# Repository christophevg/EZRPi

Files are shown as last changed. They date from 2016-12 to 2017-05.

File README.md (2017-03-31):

# EZRPi
Raspberry Pi HAT with a Silicon Labs EZR32 Sub-GHz MCU  
Christophe VG (<contact@christophe.vg>)  
[http://christophe.vg/embedded/EZRPi](http://christophe.vg/embedded/EZRPi)

## Introduction

Using the EZRPi HAT one can give access to sub-GHz network protocols to a Raspberry Pi. An example of such protocol is Dash7. Dash7 is a specification for an ultra low power network stack, operating within the sub-GHz spectrum. The [Dash7 Open Source Stack (OSS-7)](https://github.com/MOSAIC-LoPoW/dash7-ap-open-source-stack) can be flashed onto the EZR to turn it into a modem, accessible from the Raspberry Pi. On the Pi, one then could talk to this modem using [pyd7a](https://github.com/MOSAIC-LoPoW/pyd7a) a collection of Python modules, supporting the DASH7 Alliance Protocol in general, and OSS-7 in particular..

This repository contains all design and implementation source files of this generic sub-GHz Raspberry Pi HAT.

## Version 1

On Thursday March 30, I was able to assemble the first EZRPi:

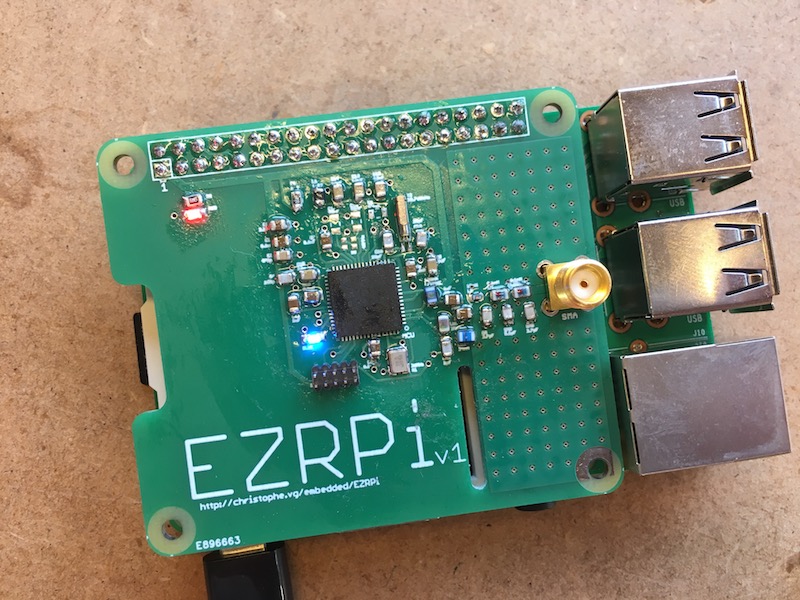
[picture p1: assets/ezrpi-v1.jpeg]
EZRPi v1


The design includes a standard 868MHz setup of the EZR32 and two LEDs for minimal debugging/feedback.

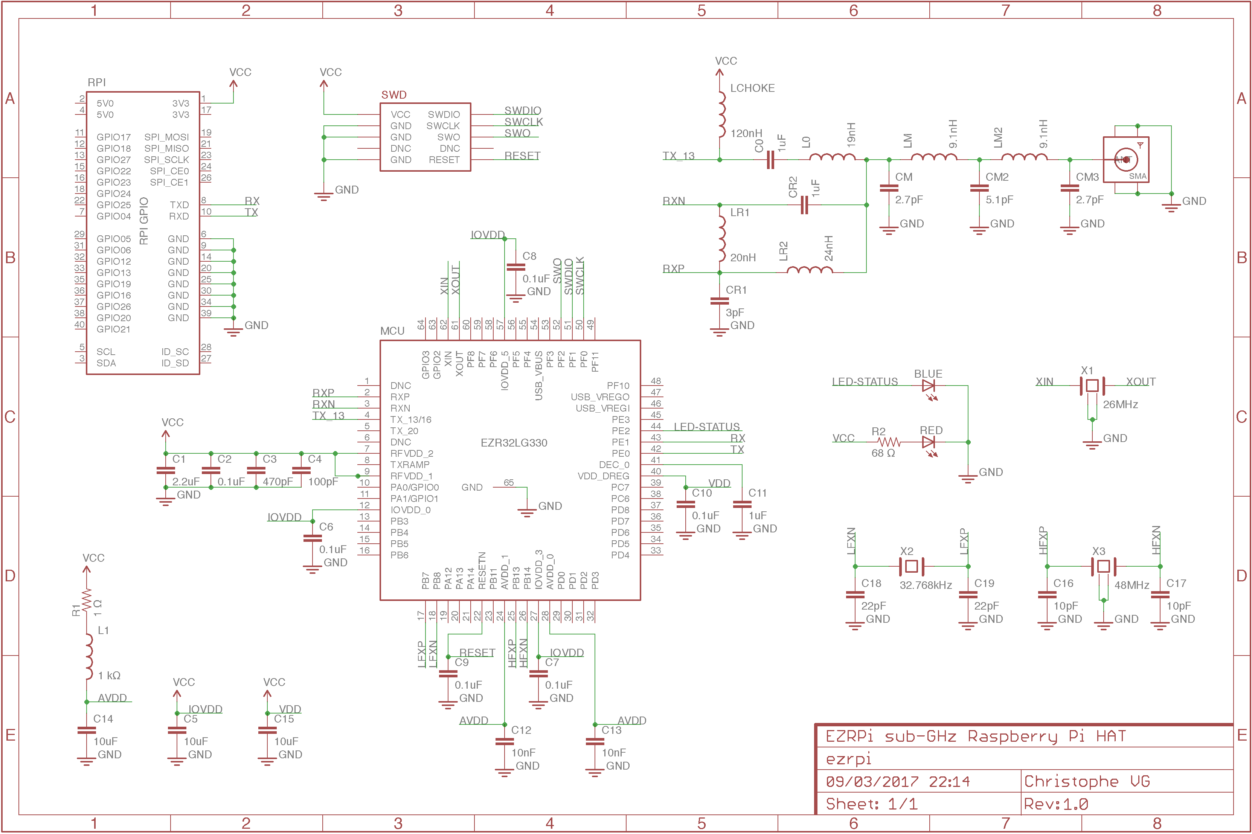
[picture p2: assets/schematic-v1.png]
Schematic v1


The board is a 2-layer PCB based on the official Raspberry Pi HAT board specification.

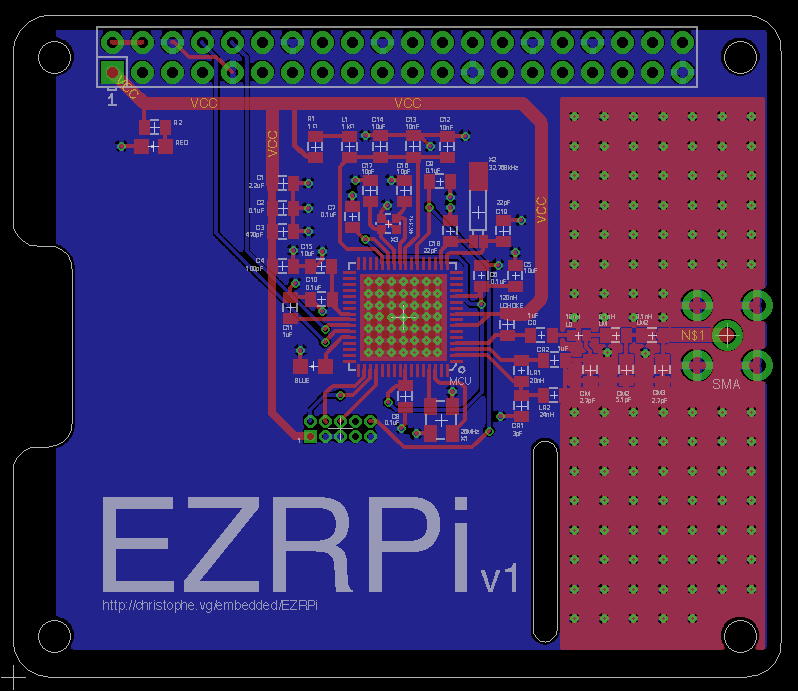
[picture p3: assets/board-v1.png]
Board v1


## Software

In the `src/` folder a first small test application is included: [`blink`](src/blink). It requires the `Gecko SDK`, which is included as a submodule in the `lib/` folder.

### OSS-7 Support

As of [Friday March 21](https://github.com/MOSAIC-LoPoW/dash7-ap-open-source-stack/pull/51), the [Dash7 Open Source Stack](https://github.com/MOSAIC-LoPoW/dash7-ap-open-source-stack) now also includes a platform definition for the EZRPi. This makes it super-easy to add Dash7 support to the Raspberry Pi:

```bash
$ git clone https://github.com/MOSAIC-LoPoW/dash7-ap-open-source-stack
Cloning into 'dash7-ap-open-source-stack'...
remote: Counting objects: 39483, done.
remote: Compressing objects: 100% (291/291), done.
remote: Total 39483 (delta 164), reused 0 (delta 0), pack-reused 39191
Receiving objects: 100% (39483/39483), 71.42 MiB | 8.46 MiB/s, done.
Resolving deltas: 100% (27893/27893), done.

$ cd dash7-ap-open-source-stack

$ mkdir build

$ cd build

$ cmake ../stack/ \
        -DCMAKE_TOOLCHAIN_FILE=../stack/cmake/toolchains/gcc-arm-embedded.cmake \
        -DPLATFORM=EZRPi \
        -DAPP_SENSOR_PUSH=on \
        -DFRAMEWORK_LOG_ENABLED=yes \
        -DFRAMEWORK_DEBUG_ASSERT_MINIMAL=y
-- Cross-compiling using gcc-arm-embedded toolchain
-- Cross-compiling using gcc-arm-embedded toolchain
-- The C compiler identification is GNU 4.9.3
-- The CXX compiler identification is GNU 4.9.3
-- Detecting C compiler ABI info
-- Detecting C compiler ABI info - failed
-- Detecting C compile features
-- Detecting C compile features - failed
-- Detecting CXX compiler ABI info
-- Detecting CXX compiler ABI info - failed
-- Detecting CXX compile features
-- Detecting CXX compile features - failed
-- detected supported platforms: EFM32GG_STK3700 EFM32HG_STK3400 EZR32LG_Octa EZR32LG_USB01 EZR32LG_WSTK6200A EZRPi OCTA_Gateway stm32f4_discovery
-- selected platform: EZRPi
-- The ASM compiler identification is GNU
-- Found assembler: /usr/local/bin/arm-none-eabi-gcc
-- Added chip ezr32lg
-- Added chip si4460
-- Configuring done
-- Generating done
-- Build files have been written to: /Users/xtof/dash7-ap-open-source-stack/build

$ make
Scanning dependencies of target CHIP_SI4460
[  1%] Building C object framework/hal/platforms/platform/chips/si4460/CMakeFiles/CHIP_SI4460.dir/si4460.c.obj
...
[ 98%] Building C object apps/sensor_push/CMakeFiles/sensor_push.elf.dir/version.c.obj
[100%] Linking C executable sensor_push.elf
[100%] Built target sensor_push.elf

$ make flash-sensor_push
[ 14%] Built target d7ap
[ 22%] Built target CHIP_SI4460
...
Downloading file [sensor_push.bin]...
Comparing flash   [100%] Done.
Erasing flash     [100%] Done.
Programming flash [100%] Done.
Verifying flash   [100%] Done.
J-Link: Flash download: Flash programming performed for 3 ranges (77824 bytes)
J-Link: Flash download: Total time needed: 1.960s (Prepare: 0.052s, Compare: 0.062s, Erase: 0.933s, Program: 0.896s, Verify: 0.008s, Restore: 0.007s)
O.K.

Loading binary file sensor_push.bin
Reading 81476 bytes data from target memory @ 0x00000000.
Verify successful.

Reset delay: 0 ms
Reset type NORMAL: Resets core & peripherals via SYSRESETREQ & VECTRESET bit.

Script processing completed.

[100%] Built target flash-sensor_push

```

The EZRPi has been tested against the EZR32LG_USB01 and bi-directional communication was achieved.

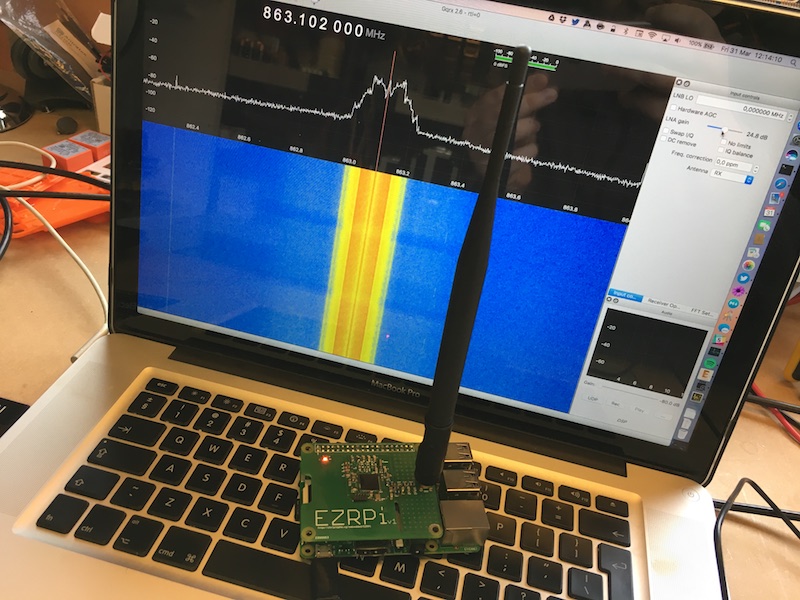
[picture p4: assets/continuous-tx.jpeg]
It's Alive


## Thanks

Although merely a software-implementation option, many thanks go out to the Dash7 Alliance and the OSS-7 team for creating the Dash7 network stack specification in all openness. Special thanks go out to Maarten W. for his support in making this project a reality.

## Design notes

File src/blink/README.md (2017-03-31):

# EZRPi Blink

This example is the most basic example for testing the minimal capabilities of the EZRPi. It only uses the standard [Gecko SDK](../lib/Gecko_SDK) to blink the blue LED.

## Setup

Mount the EZRPi on a Raspberry Pi and power the Pi. The red led near the Pi header should light up, indicating that the EZRPi also is powered.

## Building

```bash
$ make
*** compiling ../../lib/Gecko_SDK/platform/Device/SiliconLabs/EZR32LG/Source/system_ezr32lg.c
*** assembling ../../lib/Gecko_SDK/platform/Device/SiliconLabs/EZR32LG/Source/GCC/startup_ezr32lg.S
*** compiling ../../lib/Gecko_SDK/platform/emlib/src/em_assert.c
*** compiling ../../lib/Gecko_SDK/platform/emlib/src/em_cmu.c
*** compiling ../../lib/Gecko_SDK/platform/emlib/src/em_ebi.c
*** compiling ../../lib/Gecko_SDK/platform/emlib/src/em_emu.c
*** compiling ../../lib/Gecko_SDK/platform/emlib/src/em_gpio.c
*** compiling ../../lib/Gecko_SDK/platform/emlib/src/em_system.c
*** compiling ../../lib/Gecko_SDK/platform/emlib/src/em_usart.c
*** compiling blink.c
*** linking .build/blink.out
*** creating .build/blink.bin
```

## Programming

To program the EZR32, I use a programmer and software from [Segger](https://www.segger.com). Other solutions are possible, but I'm not covering them.

```bash
$  make program
*** generating programming script .build/flash.script
*** programming
SEGGER J-Link Commander V6.14b (Compiled Mar  9 2017 08:48:44)
DLL version V6.14b, compiled Mar  9 2017 08:48:31
...
Downloading file [blink/blink.bin]...
Comparing flash   [100%] Done.
Erasing flash     [100%] Done.
Programming flash [100%] Done.
Verifying flash   [100%] Done.
J-Link: Flash download: Flash programming performed for 1 range (6144 bytes)
J-Link: Flash download: Total time needed: 0.184s (Prepare: 0.066s, Compare: 0.004s, Erase: 0.000s, Program: 0.103s, Verify: 0.001s, Restore: 0.009s)
O.K.
Reset delay: 0 ms
Reset type NORMAL: Resets core & peripherals via SYSRESETREQ & VECTRESET bit.

```

You now should have a blinking blue led near the lower left corner of the microcontroller.

EZRPi v1

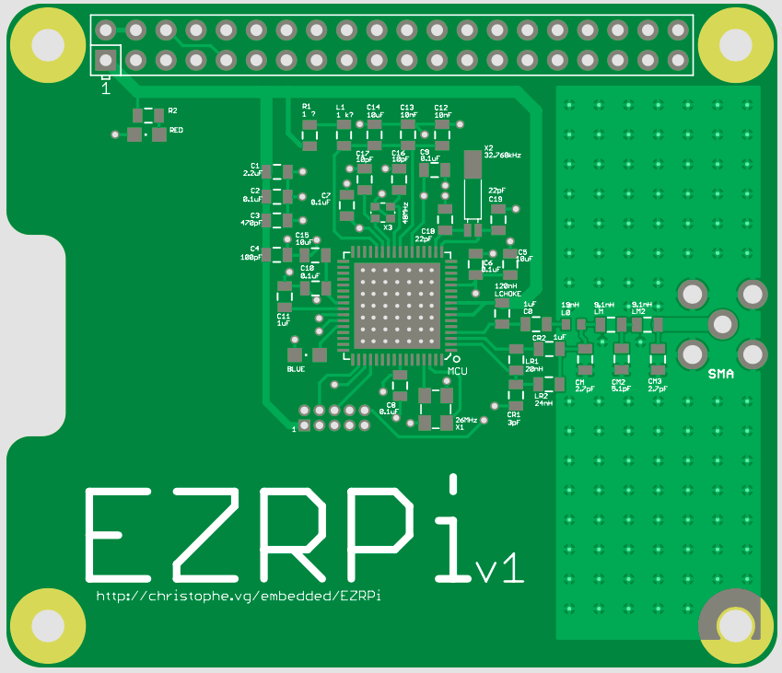
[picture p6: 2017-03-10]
assets/ec-v1.png

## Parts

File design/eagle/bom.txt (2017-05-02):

Partlist exported from /Users/xtof/Workspace/EZRPi/design/eagle/ezrpi.sch at 31/03/2017 21:42

Qty Value      Device           Package                 Parts                   Description   
2              LEDCHIPLED_0805  CHIPLED_0805            BLUE, RED               LED           
1              SMACONNECTOR     SMA90_DIP               SMA                     SMA Connector 
6   0.1uF      CAP0805          0805                    C2, C6, C7, C8, C9, C10 Capacitor     
1   1 kΩ       INDUCTOR0805     0805                    L1                      Inductors     
1   1 Ω        RESISTOR0805-RES 0805                    R1                      Resistor      
1   100pF      CAP0805          0805                    C4                      Capacitor     
2   10nF       CAP0805          0805                    C12, C13                Capacitor     
2   10pF       CAP0805          0805                    C16, C17                Capacitor     
3   10uF       CAP0805          0805                    C5, C14, C15            Capacitor     
1   120nH      INDUCTOR0805     0805                    LCHOKE                  Inductors     
1   19nH       INDUCTOR0402     C0402                   L0                      Inductors     
3   1uF        CAP0805          0805                    C0, C11, CR2            Capacitor     
1   2.2uF      CAP0805          0805                    C1                      Capacitor     
2   2.7pF      CAP0805          0805                    CM, CM3                 Capacitor     
1   20nH       INDUCTOR0805     0805                    LR1                     Inductors     
2   22pF       CAP0805          0805                    C18, C19                Capacitor     
1   24nH       INDUCTOR0805     0805                    LR2                     Inductors     
1   26MHz      ABM8             ABM8                    X1                                    
1   32.768kHz  MS3V-T1R         MS3V-T1R                X2                                    
1   3pF        CAP0805          0805                    CR1                     Capacitor     
1   470pF      CAP0805          0805                    C3                      Capacitor     
1   48MHz      ABM11            ABM11                   X3                                    
1   5.1pF      CAP0805          0805                    CM2                     Capacitor     
1   68 Ω       RESISTOR0805-RES 0805                    R2                      Resistor      
2   9.1nH      INDUCTOR0805     0805                    LM, LM2                 Inductors     
1   EZR32LG330 EZR32LG330       QFN64G-0.5-9X9MM        MCU                                   
1   FTSH2X5    FTSH2X5          HEADER2X5               SWD                                   
1   RPI3_HAT   RPI3_HAT         RASPI_BOARD_B+HAT_DF_CF RPI

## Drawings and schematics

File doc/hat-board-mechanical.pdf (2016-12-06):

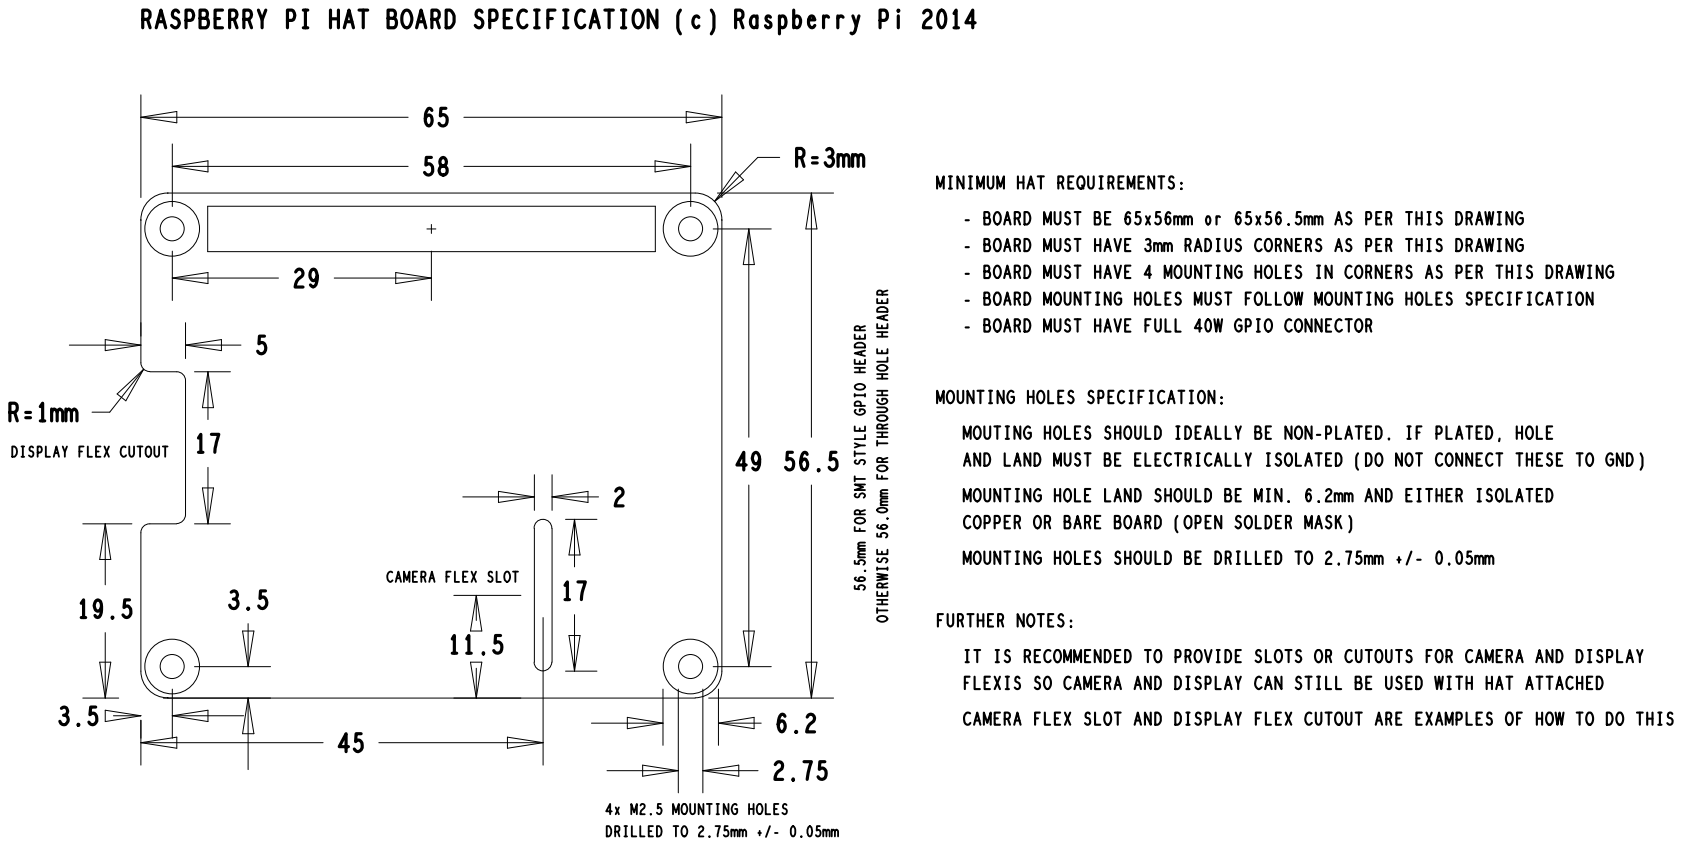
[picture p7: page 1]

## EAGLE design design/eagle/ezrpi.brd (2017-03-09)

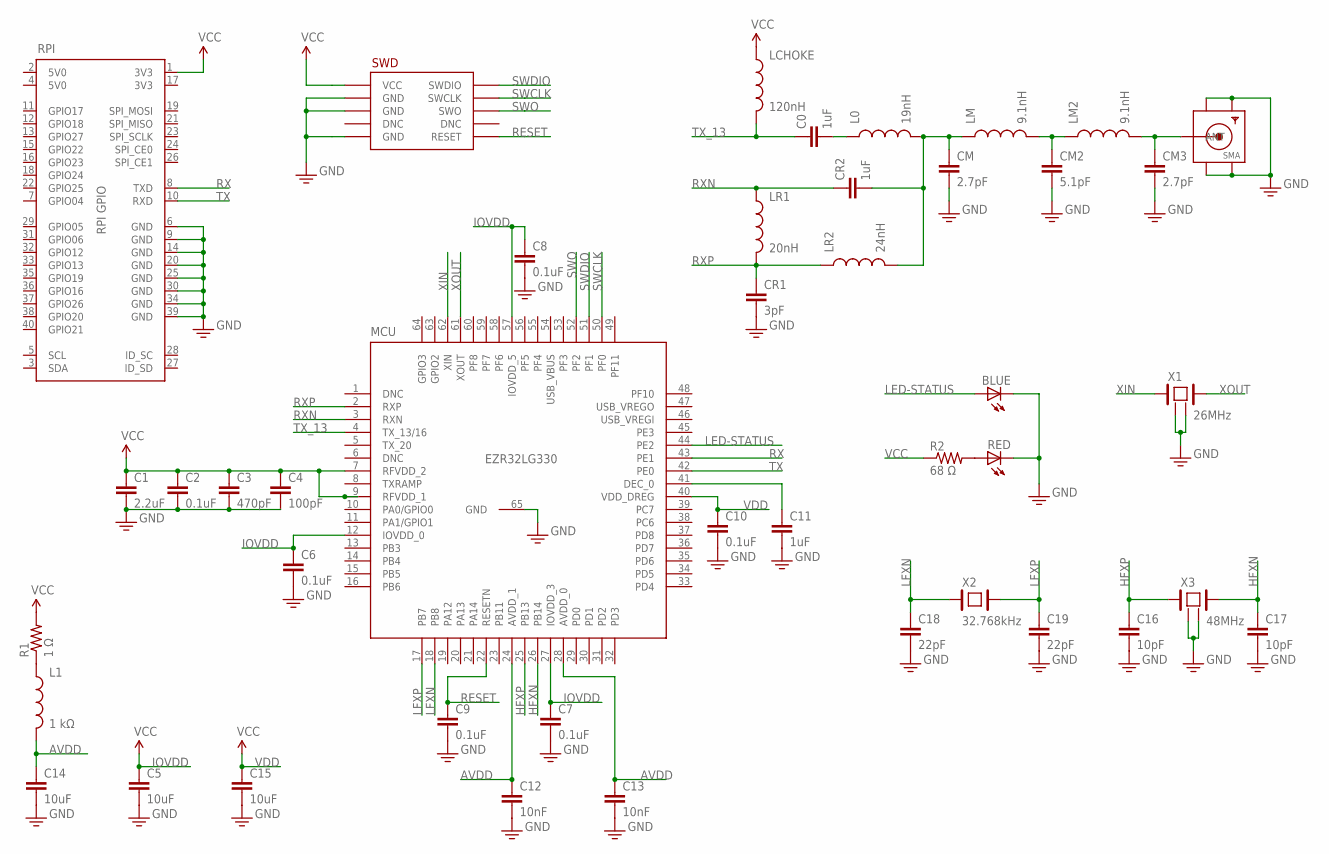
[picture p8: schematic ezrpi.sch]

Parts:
BLUE: LEDCHIPLED_0805; CHIPLED_0805
C0, C11: 1uF; 0805
C1: 2.2uF; 0805
C2, C6, C7, C8, C9, C10: 0.1uF; 0805
C3: 470pF; 0805
C4: 100pF; 0805
C5, C14, C15: 10uF; 0805
C12, C13: 10nF; 0805
C16, C17: 10pF; 0805
C18, C19: 22pF; 0805
CM, CM3: 2.7pF; 0805
CM2: 5.1pF; 0805
CR1: 3pF; 0805
CR2: 1uF; 0805
L0: 19nH; C0402
L1: 1 kΩ; 0805
LCHOKE: 120nH; 0805
LM, LM2: 9.1nH; 0805
LR1: 20nH; 0805
LR2: 24nH; 0805
MCU: EZR32LG330; QFN64G-0.5-9X9MM
R1: 1 Ω; 0805
R2: 68 Ω; 0805
RED: LEDCHIPLED_0805; CHIPLED_0805
RPI: RPI3_HAT; RASPI_BOARD_B+HAT_DF_CF
SMA: SMACONNECTOR; SMA90_DIP
SWD: FTSH2X5; HEADER2X5
X1: 26MHz; ABM8
X2: 32.768kHz; MS3V-T1R
X3: 48MHz; ABM11

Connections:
3V3: RPI.17 (3V3)
5V0: RPI.2 (5V0), RPI.4 (5V0)
AVDD: C12.1, C13.1, C14.1, L1.2, MCU.24 (AVDD_1), MCU.28 (AVDD_0)
GND: BLUE.C, C1.2, C2.2, C3.2, C4.2, C5.2, C6.2, C7.2, C8.2, C9.2, C10.2, C11.2, C12.2, C13.2, C14.2, C15.2, C16.2, C17.2, C18.2, C19.2, CM.2, CM2.2, CM3.2, CR1.2, MCU.65 (GND), RED.C, RPI.6 (GND), RPI.9 (GND), RPI.14 (GND), RPI.20 (GND), RPI.25 (GND), RPI.30 (GND), RPI.34 (GND), RPI.39 (GND), SMA.GND1, SMA.GND2, SMA.GND3, SMA.GND4, SWD.P$3 (GND), SWD.P$5 (GND), SWD.P$9 (GND), X1.2 (GND), X1.4 (GND), X3.2 (GND), X3.4 (GND)
HFXN: C17.1, MCU.26 (PB14), X3.3
HFXP: C16.1, MCU.25 (PB13), X3.1
IOVDD: C5.1, C6.1, C7.1, C8.1, MCU.12 (IOVDD_0), MCU.27 (IOVDD_3), MCU.57 (IOVDD_5)
LED-STATUS: BLUE.A, MCU.44 (PE2)
LFXN: C18.1, MCU.18 (PB8), X2.1
LFXP: C19.1, MCU.17 (PB7), X2.2
unnamed: CM3.1, LM2.2, SMA.ANTENNA (ANT)
unnamed: C11.1, MCU.41 (DEC_0)
unnamed: CM2.1, LM.2, LM2.1
unnamed: L1.1, R1.1
unnamed: C0.2, L0.1
unnamed: CM.1, CR2.2, L0.2, LM.1, LR2.2
unnamed: R2.2, RED.A
RESET: C9.1, MCU.22 (RESETN), SWD.P$10 (RESET)
RX: MCU.43 (PE1), RPI.8 (TXD)
RXN: CR2.1, LR1.1, MCU.3 (RXN)
RXP: CR1.1, LR1.2, LR2.1, MCU.2 (RXP)
SWCLK: MCU.50 (PF0), SWD.P$4 (SWCLK)
SWDIO: MCU.51 (PF1), SWD.P$2 (SWDIO)
SWO: MCU.52 (PF2), SWD.P$6 (SWO)
TX: MCU.42 (PE0), RPI.10 (RXD)
TX_13: C0.1, LCHOKE.2, MCU.4 (TX_13/16)
VCC: C1.1, C2.1, C3.1, C4.1, LCHOKE.1, MCU.7 (RFVDD_2), MCU.9 (RFVDD_1), R1.2, R2.1, RPI.1 (3V3), SWD.P$1 (VCC)
VDD: C10.1, C15.1, MCU.40 (VDD_DREG)
XIN: MCU.62 (XIN), X1.1
XOUT: MCU.61 (XOUT), X1.3

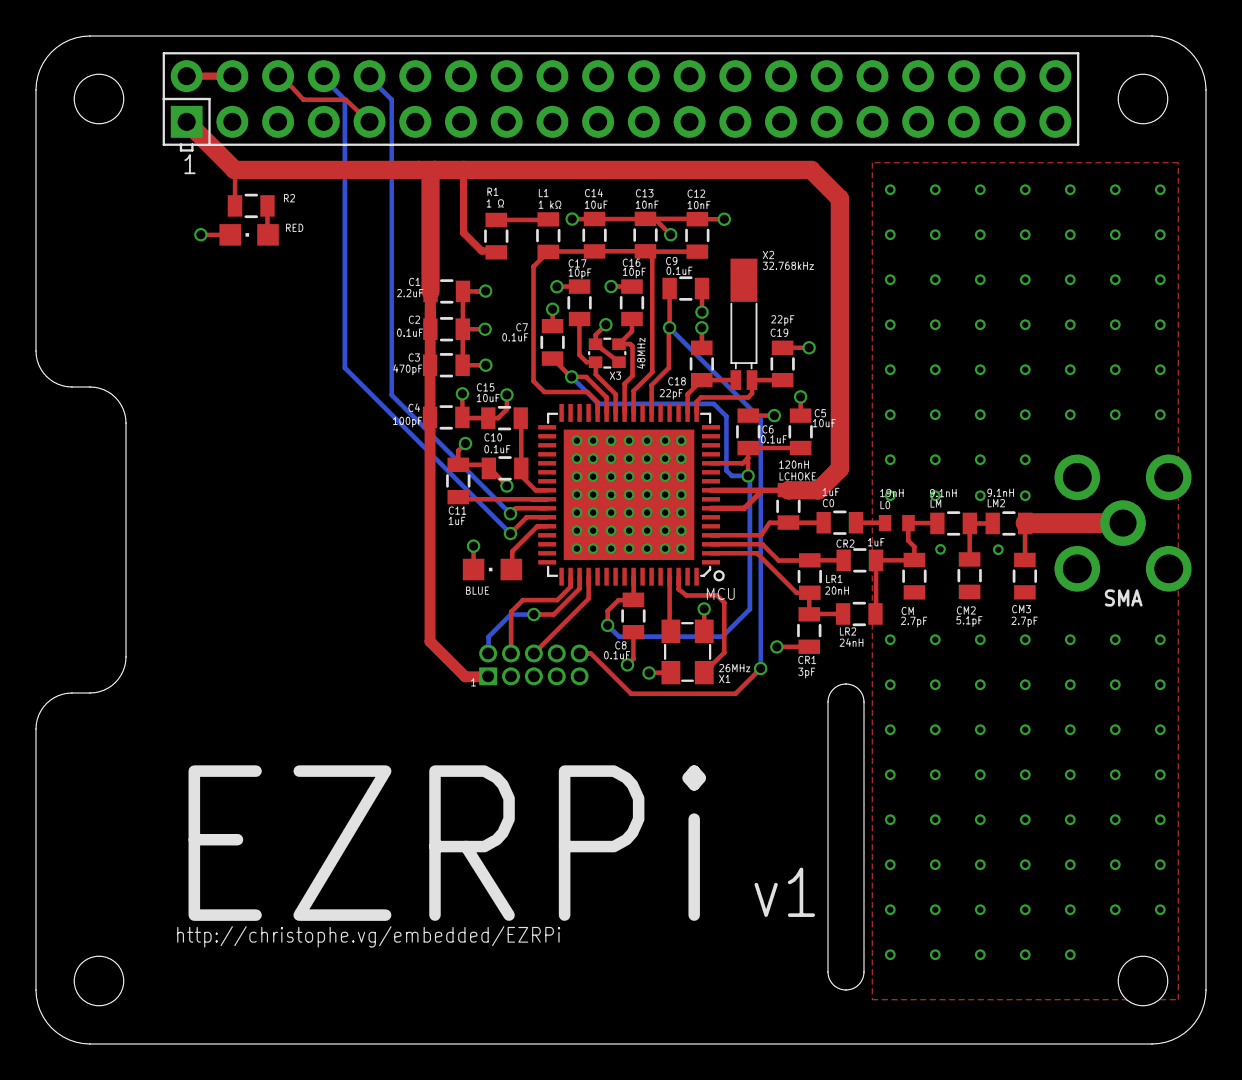
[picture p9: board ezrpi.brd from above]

Board: 2 copper layers, 65.0 x 56.0 mm, 43 parts (0 on the bottom side), 29 nets.

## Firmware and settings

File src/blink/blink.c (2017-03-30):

#include <stdint.h>
#include <stdbool.h>

#include "em_device.h"
#include "em_chip.h"
#include "em_cmu.h"
#include "em_emu.h"
#include "em_gpio.h"

// EZRPi
#define LED_PORT gpioPortE
#define LED_PIN  2

volatile uint32_t ticks;

void SysTick_Handler(void) { ticks++; }

void delay(uint32_t ms) {
  uint32_t now;
  now = ticks;
  while( (ticks - now) < ms );
}

int main(void) {
  CHIP_Init();

  CMU_ClockEnable(cmuClock_GPIO, true);

  if( SysTick_Config(CMU_ClockFreqGet(cmuClock_CORE) / 1000) ) { while(true); }

  GPIO_PinModeSet(LED_PORT, LED_PIN, gpioModePushPull, 0);

  while(true) {
    GPIO_PinOutToggle(LED_PORT, LED_PIN);    
    delay(1000);
  }
}

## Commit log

2016-12-06 added initial setup of MCU + decoupling
    [pi-7.sch]
2016-12-08 redesigned to match AN0016 + added JTAG (6pins)
    [pi-7.sch]
2016-12-08 added crystals
    [pi-7.sch]
2017-02-15 rebranded project to generic EZRPi sub-GHz HAT
    [ezrpi.brd, ezrpi.sch]
2017-03-08 completed schematic, started work on board design
    [ezrpi.brd, ezrpi.sch]
2017-03-09 completed schematic and first board layout
    [ezrpi.brd, ezrpi.sch]
2017-03-09 fixed some design rules violations
    [ezrpi.brd]
2017-03-09 fixed incorrect pin connection on IOVDD_0
    [ezrpi.brd, ezrpi.sch]
2017-03-09 unified cap value 100nF = 0.1uF
    [ezrpi.brd, ezrpi.sch]
2017-03-09 added top ground plane, fixed silk & naming
    [ezrpi.brd, ezrpi.sch]
2017-03-09 moved tValues to tNames (EC)
    [ezrpi.brd]
2017-03-09 added some green-(silk-)space filling ;-)
    [ezrpi.brd]
2017-03-09 added url
    [ezrpi.brd]
2017-03-09 added LEDs, improved traces, 50 Ω line, added vias
    [ezrpi.brd, ezrpi.sch]
2017-03-09 added more fence vias
    [ezrpi.brd]
2017-03-10 added “thanks” section to README
2017-03-29 added draft “blink” example using emlib & co
2017-03-30 setup for correct EZR(Pi)
    [blink.c]
2017-05-02 update BOM
